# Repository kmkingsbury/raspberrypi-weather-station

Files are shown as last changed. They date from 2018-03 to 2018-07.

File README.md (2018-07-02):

# raspberry-pi-weatherstation

Rebuild of a Pi powered weather station. The origial I did an instructable for (https://www.instructables.com/id/Complete-DIY-Raspberry-Pi-Weather-Station-with-Sof/) this one uses all off the self parts.

And wrote up a few thoughts about the project on my blog as well: 
https://spaceman-labs.com/2018/07/raspberry-pi-weather-station-mk2/

Uses a few standard sensors to track weather data:
- Temperature - comes from 2 sensors the BMP and the DHT.
- Soil temperature
- Soil humidity
- Light - via a photoresistor. The Higher the number the darker out.
- Pressure
- Humidity
- 2 Air sensors - One does more dust and smoke, air quality. The other looks for gases like propane and butane.
- Wind speed
- Wind dir
- Rain Gauge
- Lightning detector - Currently having issues so commented out.

The analog sensors run through the MCP3008 chip to get converted to a digital reading.

The wiring and circuit boards are in the schematics directory and is a Fritzing file. There are also PDFs I used to print the PCB to thermal transfer paper and burn the Copper circuit boards. There are two boards: 1 in the main station for the MCP3008 A/D converter and photo resistor, and the 2nd is a "remote" unit that goes in the Amrite housing and does the air sensing, pressure, temp, and humidity, via 2 air sensors, the DHT, and the BMP.

Data is logged to a postgres table as well as a CSV file and the CSV file is rotated out nightly. The log file also contains some of the data and other debug statements.

Some frontend code is supplied to display/graph the data using Google Charts. This uses PHP to write javascript code, so it's far from ideal.
Also needs more reusable code, since a bug or change needs to go across all the pages and I've currently not been fixing that. Timeframes are roughly 24 hrs and 7-days (for the files ending in 2). Currently very buggy and titles/labels aren't very accurate (months in javascript start at 0 not 1). Will probably rewrite the frontend to something like NodeJS that will integrate easier with Google Charts (or another plotting package)

I used Gitlab and gitlab pipelines to do some automated CI and testing so the gitlab-ci is provided for some of that.

# Contents
Name | Description
-----|------------
`bom.md` | Bill of Materials - List of parts, counts, approximate prices and where to find.
`schematics/`| Fritzing Schematics for electronics
`station-code/`| Python3 Code.
`station-code/collectweather.py`| Main code for collecting weather data.
`README.md`|This file
`LICENSE`|Apache 2.0 License
`frontend/`| Docker container from running PHP scripts to display the data.
`structure.sql` | Postgresql Data schema.

# Pi Setup
- apt-get update
- apt-get upgrade
- apt-get dist-upgrade
- apt-get autoremove
- Turn on Interfacing Options:
    - SPI
    - I2C
    - 1-wire

# Python Packages
- sudo apt-get install libyaml-dev
- pip3 install pyyaml
- pip3 install structlog
- pip3 install numpy
- sudo apt-get install build-essential python-dev python3-dev
- sudo pip install psycopg2

# Postgresql Setup
- sudo apt-get install postgresql-9.6
- apt install postgresql libpq-dev postgresql-client postgresql-client-common
- sudo update-rc.d postgresql enable
- sudo su postgres
- createuser weatherstation -P --interactive
- createdb weatherstation
- create table using structure.sql
- GRANT ALL PRIVILEGES ON TABLE weatherdata TO weatherstation;
- https://www.howtoforge.com/tutorial/postgresql-replication-on-ubuntu-15-04/

# 3rd Party Sensor Modules:
Add SSH key:
```
eval $(ssh-agent -s)
ssh-add ~/.ssh/other_id_rsa
```
Checkout Modules, run sudo python setup.py install
```
git clone https://github.com/PrzemoF/bmp183.git
git clone git://gist.github.com/3151375.git
git clone https://github.com/adafruit/Adafruit_Python_DHT.git
git clone https://github.com/adafruit/Adafruit_Python_GPIO.git
git clone https://github.com/adafruit/Adafruit_Python_MCP3008.git
```

Docker testing image:
```
docker build -t gitlab:4567/lab-projects/raspberry-pi-weatherstation .
```

# Components
- Leverages gitlab and pipelines to do tasks
- Started with Database is Postgresql and the pgadmin interface to get GUI
representation.

# License and Authors

Author:: Kevin Kingsbury ([@kmkingsbury](https://twitter.com/kmkingsbury))

Apache 2.0

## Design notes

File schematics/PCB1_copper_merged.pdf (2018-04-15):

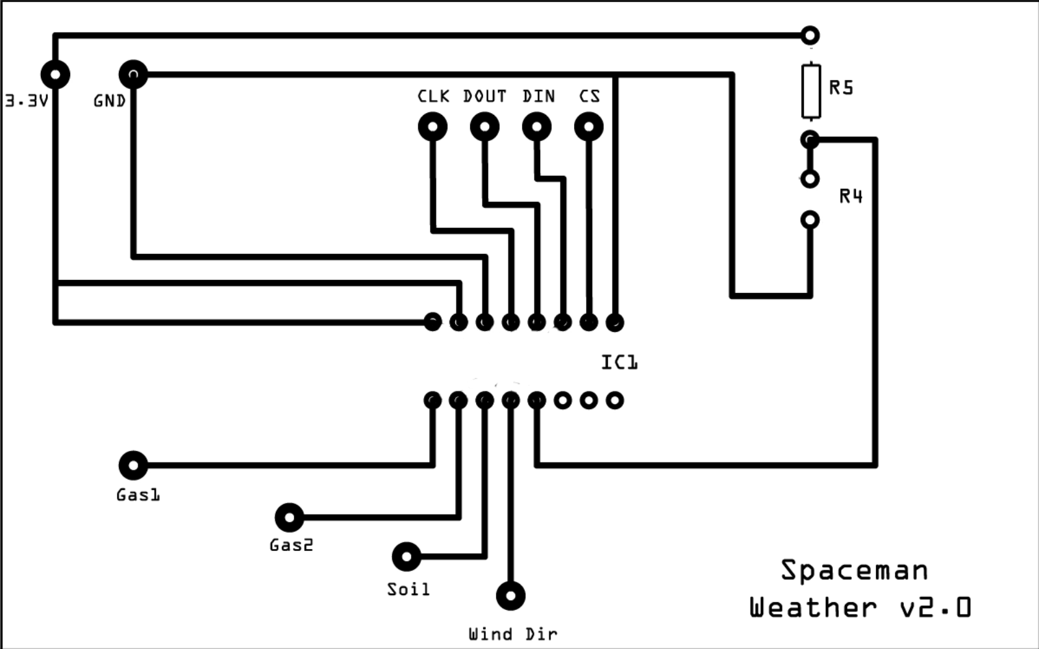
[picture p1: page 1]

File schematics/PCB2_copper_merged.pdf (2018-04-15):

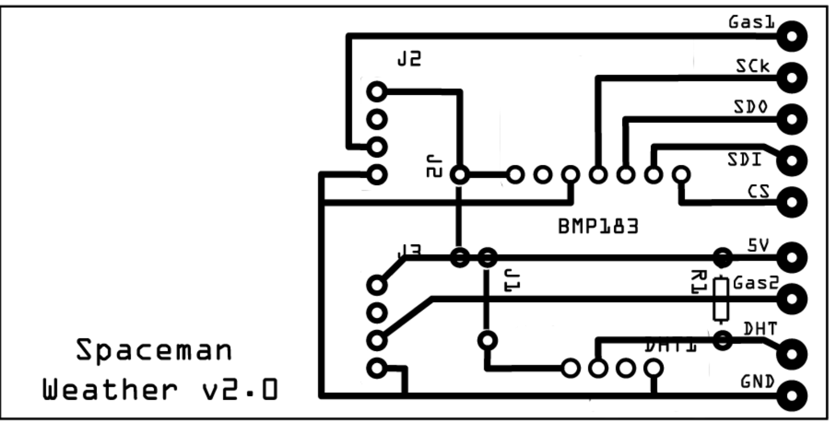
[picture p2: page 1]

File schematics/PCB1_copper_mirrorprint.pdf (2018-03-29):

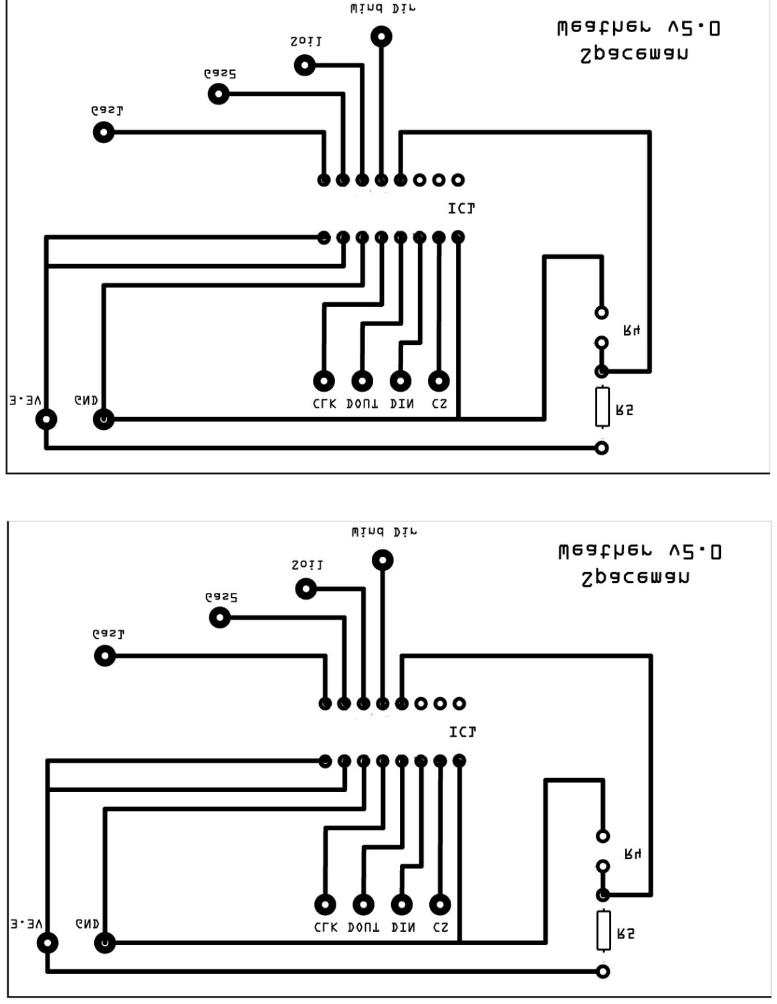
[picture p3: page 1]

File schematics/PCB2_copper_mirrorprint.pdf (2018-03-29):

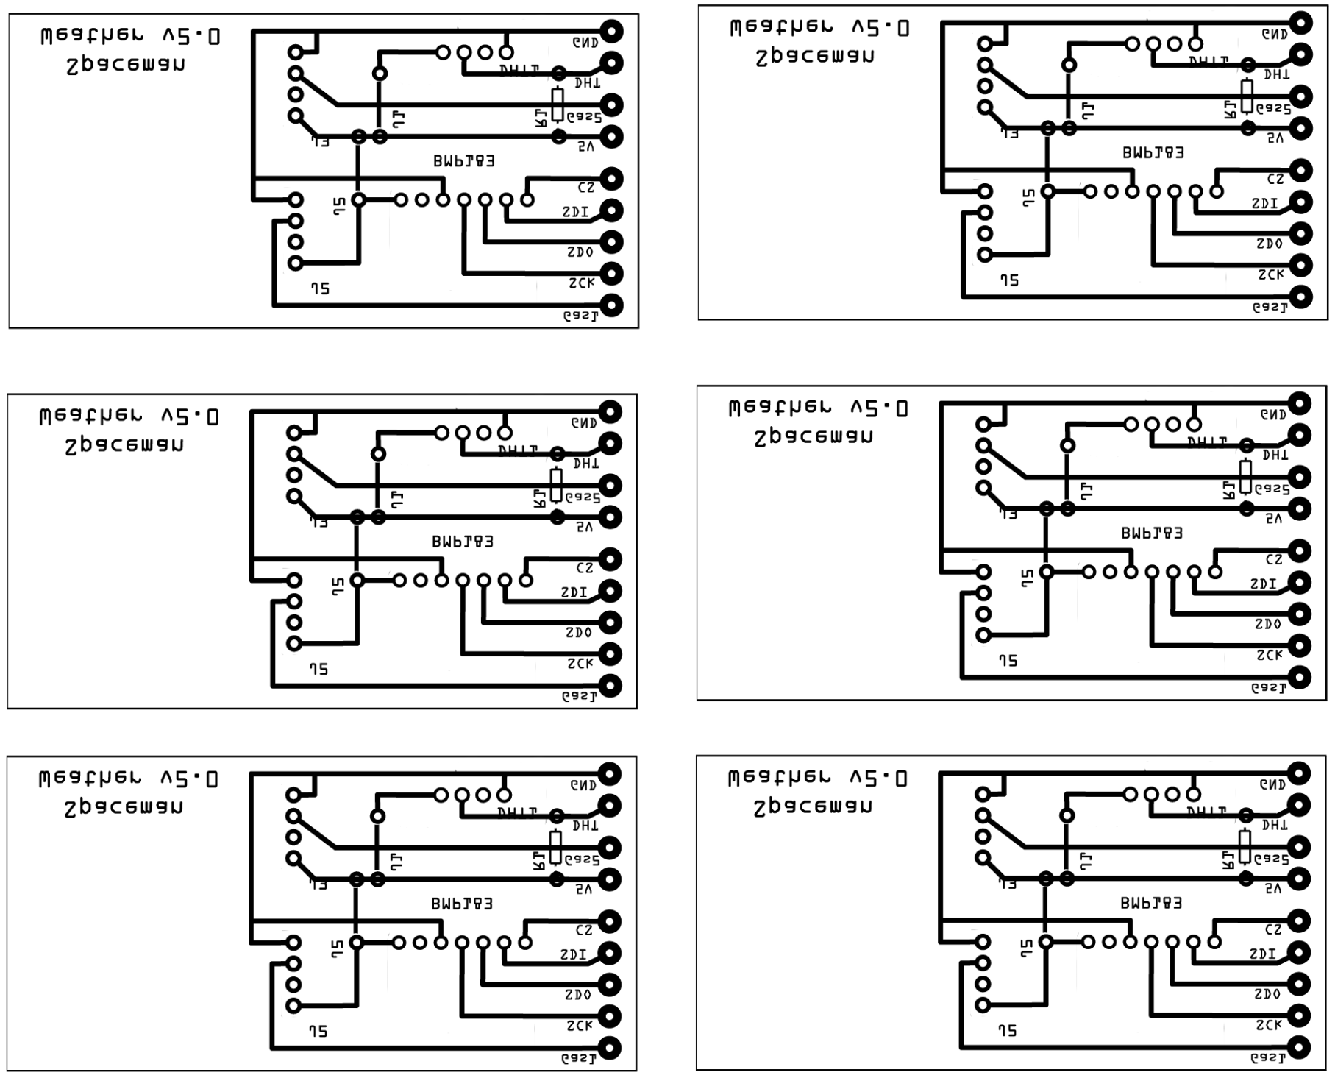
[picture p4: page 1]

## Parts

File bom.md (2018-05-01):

# Bill of Materials

Item | Count | Price | Url/Source
-----|-------|-------|-----------
Arduino | 1 | $19.00 | http://world.arduino.org/en/arduino/arduino-uno-smd-rev3.html
Waterproof DS18B20 Digital temperature sensor | 1 | |
BMP183 - barometric pressure and temperature | 1 | | https://www.adafruit.com/product/1900
DHT11 Temperature & Humidity | 1 | | https://www.adafruit.com/product/386
Soil Moisture Sensor | 1 | | https://www.sparkfun.com/products/13322
SainSmart TGS2600 Air Contaminants | 1 | |
Sunfounder MQ-2 Gas Sensor Module | 1 | |
Wind and Rain Sensors | 1 | | https://www.sparkfun.com/products/8942
AcuRite 06054M Temperature & Humidity Solar Radiation Shield | 1 | | http://a.co/5gr22Gu
Ribbon cable
Copper PC Board 12 x 12 Single Sided | 1 | | http://a.co/jdnRazi
HAMMOND 1591ASBK ENCLOSURE, MULTIPURPOSE, ABS, BLACK | 1 | | http://a.co/6SK6K87

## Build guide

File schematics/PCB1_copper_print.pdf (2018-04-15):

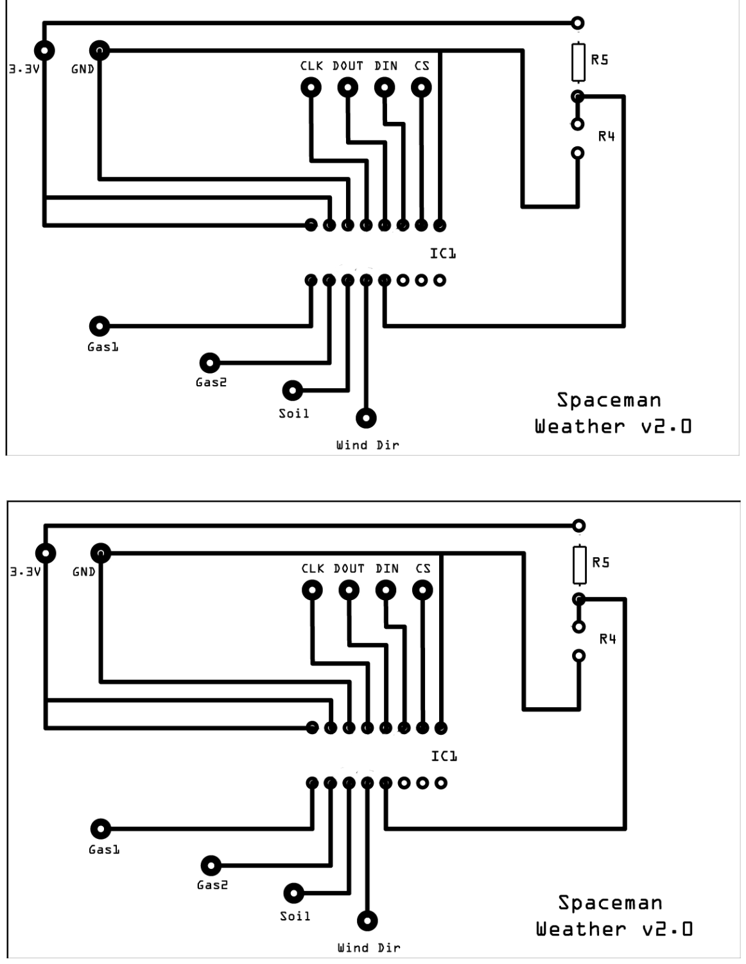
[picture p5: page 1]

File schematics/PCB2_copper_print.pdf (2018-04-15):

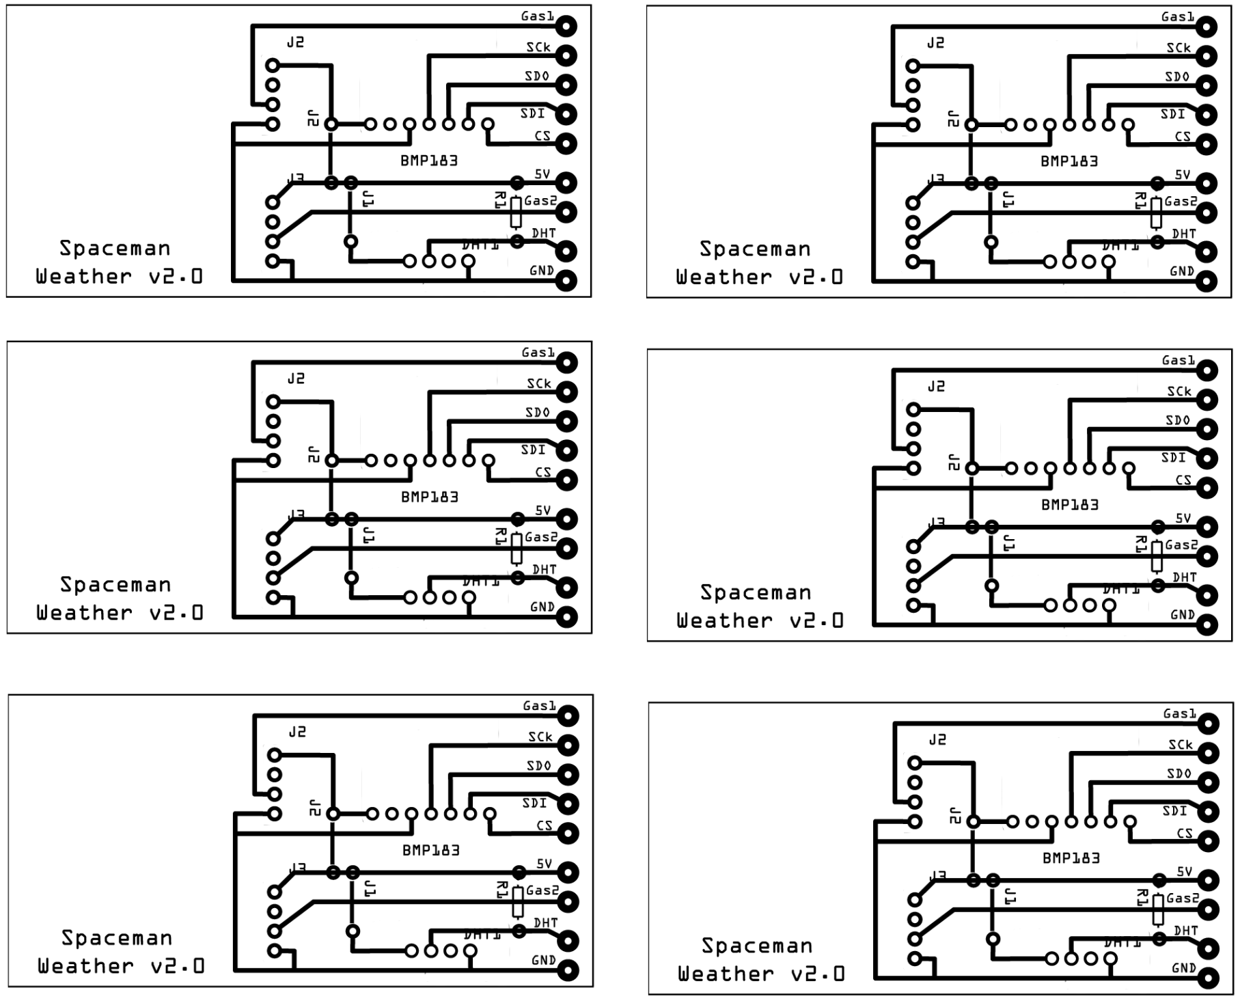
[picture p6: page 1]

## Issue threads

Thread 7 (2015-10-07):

gps/anemometer

OKenobi, 2015-10-07:
Hi there. This is a nice project, indeed. Great job.
I just want to save me some time by not building the wind speed and rain collector. Do you think these items will work with the rest of the components you used? (see links below, please):

GPS:
http://www.adafruit.com/product/746

Anemometer:
http://www.adafruit.com/product/1733

Couldn't find anything as for rain collector bucket that comes pre-assembled and to empty itself.

Thank you.

kmkingsbury, 2015-10-09:
Yes, looks like those will totally work.

There's also these guys to get the whole set without making them. I picked one up:
https://www.sparkfun.com/products/8942
And here:
http://www.kr4.us/weather-meters.html

OKenobi, 2015-10-09:
Thank you. I'll definitely look into it.

Closed 2015-10-09.

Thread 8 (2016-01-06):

stuck in the middle...

OKenobi, 2016-01-06:
Happy New Year, Kevin!

Hope you'll have a blast in 2016.

I'm planning to build the weather station project you've created. got the parts but I'm stuck. I REALLY need your help, brother!
As not so experienced (yet :)) I need some guidlines connecting my components. following the diagram .fzz.file didn't help me much. I hope that you'll help me build this as I already invested time and money towards this great project.

What I have purchased so far:
RPI2/Raspberry Pi camera
Adafruit BMP180 pressure sensor
Adafruit DHT 22 humidity sensor
Adafruit MCP3008
Sparkfun Weather Meater
https://www.sparkfun.com/products/8942 (got this just to save time building it)

tested individually BMP180 and DHT22 work fine, connected to Rpi2 GPIO as:
BMP180:
VIN - Pin #1
GND - Pin #6
SCL - Pin #5
SDA - Pin #3

DHT22:
VDD - Pin #1
DATA - Pin #4
NULL
GND - Pin #6

I don't use a GPS and light sensor; What I don't know where to connect:
the Tipping Bucket Rain Gauge (2 wire conductor RJ11)
the Wind Vane (4 wire conductor on RJ11); (the Anemometer gets connected to Wind Vane with a 2 wire conductor RJ11, I guess).
I know your code is using BMP183, which is an SPI sensor as opossed the one I've purchased. Can you please give me some instructions so I can finish this? I don't want to give up on this, as I said, I've found it amazing, but I'm really stuck right now. Hope you understand my pain :)

thank you, much appreciated and looking fwd hearing from you!

Ovi
TangoRom@yahoo.com

zxPILEDRIVERxz, 2016-01-07:
You can easily set the GPS coordinates manually in the code or remove them entirely.
Rain Bucket -> Just connect one of the two wires to the pin indicated in your code (the interrupts).
Wind Vane -> I took my wind vane apart to determine which two wires i needed. I think mine were the red and black). I gave one side (Black i think) 3.3v (assuming thats what your MCP3008) is getting. The other (Red) goes to ground. In line with the Vin I have a wire going to channel 3 on the MCP3008.
Anemometer -> same as rain bucket (I think yellow and green).

MCP3008 -> http://www.raspberrypi-spy.co.uk/2013/10/analogue-sensors-on-the-raspberry-pi-using-an-mcp3008/ That link should give you a decent idea at what you are looking at. Remember, in the code as is, we are not using SPI for the MCP3008 so that link should only be used for understanding of wiring.

Software -> I had a look here and brought some of the conversions etc for windspeed: https://github.com/switchdoclabs/WeatherPi
https://github.com/switchdoclabs/SDL_Pi_Weather_80422

Notes:
-I used a 10k resistor in line with the vin side of the wind vane a lot like you would with the light sensor.
-The MCP3008 gives you a value ranging from 0 - 1023 based on voltage on that channel. You will need to be able to convert that to voltage and then into degrees (in the case of the windvane). You can find other methods for changing degrees into capital wind direction if you are interested in that.

Ex: (Only code relevant to windvane included) some of this is unnecessary.
```
GPIO.setmode(GPIO.BOARD)
SPICLK = 23 #17
SPIMISO = 21 #24
SPIMOSI = 19 #25
SPICS = 24 #27
winddir_adc = 2

# read SPI data from MCP3008 chip, 8 possible adc's (0 thru 7)
def readadc(adcnum, clockpin, mosipin, misopin, cspin):
        if ((adcnum > 7) or (adcnum < 0)):
                return -1
        GPIO.output(cspin, True)

        GPIO.output(clockpin, False)  # start clock low
        GPIO.output(cspin, False)     # bring CS low

        commandout = adcnum
        commandout |= 0x18  # start bit + single-ended bit
        commandout <<= 3    # we only need to send 5 bits here
        for i in range(5):
                if (commandout & 0x80):
                        GPIO.output(mosipin, True)
                else:
                        GPIO.output(mosipin, False)
                commandout <<= 1
                GPIO.output(clockpin, True)
                GPIO.output(clockpin, False)

        adcout = 0
        # read in one empty bit, one null bit and 10 ADC bits
        for i in range(12):
                GPIO.output(clockpin, True)
                GPIO.output(clockpin, False)
                adcout <<= 1
                if (GPIO.input(misopin)):
                        adcout |= 0x1

        GPIO.output(cspin, True)

        adcout >>= 1       # first bit is 'null' so drop it
        return adcout

# convert light into percent
def ConvertVoltage(data, supplyVolt):
  voltage = data/1024. * supplyVolt #// convert to voltage value
  return voltage

def ConvertPercent (data, supplyVolt, places):
  percent = (data / supplyVolt) * 100
  percent = round(percent,places)
  return percent

def fuzzyCompare(compareValue, value):
    VARYVALUE = 0.05
    if ( (value > (compareValue * (1.0-VARYVALUE)))  and (value < (compareValue *(1.0+VARYVALUE))) ):
        return True
    return False

def voltageToDegrees(value, defaultWindDirection):
    ADJUST3OR5 = 0.66
    PowerVoltage = 3.3
    if (fuzzyCompare(3.84 * ADJUST3OR5, value)):
        return 0.0
    if (fuzzyCompare(1.98 * ADJUST3OR5, value)):
        return 22.5
    if (fuzzyCompare(2.25 * ADJUST3OR5, value)):
	return 45
    if (fuzzyCompare(0.41 * ADJUST3OR5, value)):
	return 67.5
    if (fuzzyCompare(0.45 * ADJUST3OR5, value)):
	return 90.0
    if (fuzzyCompare(0.32 * ADJUST3OR5, value)):
	return 112.5
    if (fuzzyCompare(0.90 * ADJUST3OR5, value)):
	return 135.0
    if (fuzzyCompare(0.62 * ADJUST3OR5, value)):
	return 157.5
    if (fuzzyCompare(1.40 * ADJUST3OR5, value)):
	return 180
    if (fuzzyCompare(1.19 * ADJUST3OR5, value)):
	return 202.5
    if (fuzzyCompare(3.08 * ADJUST3OR5, value)):
 	return 225
    if (fuzzyCompare(2.93 * ADJUST3OR5, value)):
	return 247.5
    if (fuzzyCompare(4.62 * ADJUST3OR5, value)):
	return 270.0
    if (fuzzyCompare(4.04 * ADJUST3OR5, value)):
	return 292.5
    if (fuzzyCompare(4.34 * ADJUST3OR5, value)): # chart in manufacturers documentation wrong
	return 315.0
    if (fuzzyCompare(3.43 * ADJUST3OR5, value)):
	return 337.5
    return defaultWindDirection  # return previous value if not found

def windDirectionFromDegrees (Degrees):
    if (348.75 <= Degrees <= 360.00):
        hour1WindDirection = "N"
    elif (0 <= Degrees <= 11.25):
        hour1WindDirection = "N"
    elif (11.25 < Degrees <= 33.75):
        hour1WindDirection = "NNE"
    elif (33.75 < Degrees <= 56.25):
        hour1WindDirection = "NE"
    elif (56.25 < Degrees <= 78.75):
        hour1WindDirection = "ENE"
    elif (78.75 < Degrees <= 101.25):
        hour1WindDirection = "E"
    elif (101.25 < Degrees <= 123.75):
        hour1WindDirection = "ESE"
    elif (123.75 < Degrees <= 146.25):
        hour1WindDirection = "SE"
    elif (146.25 < Degrees <= 168.75):
        hour1WindDirection = "SSE"
    elif (168.75 < Degrees <= 191.25):
        hour1WindDirection = "S"
    elif (191.25 < Degrees <= 213.75):
        hour1WindDirection = "SSW"
    elif (213.75 < Degrees <= 236.25):
        hour1WindDirection = "SW"
    elif (236.25 < Degrees <= 258.75):
        hour1WindDirection = "WSW"
    elif (258.75 < Degrees <= 281.25):
        hour1WindDirection = "W"
    elif (281.25 < Degrees <= 303.75):
        hour1WindDirection = "WNW"
    elif (303.75 < Degrees <= 326.25):
        hour1WindDirection = "NW"
    elif (326.25 < Degrees < 348.75):
        hour1WindDirection = "NNW"
    else:
        hour1WindDirection = nil
    return hour1WindDirection
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
akmahusaini, 2016-12-06:
do you know the coding of wind vane with adc mcp3008? i have a project for weather station. please help us

orega35, 2017-01-24:
Hello, has anyone managed to reproduce this station? I still have a lot of questions about wiring (ldr, mpc3008 ...) all sensors have to go through the mpc3008? i use the maplin wind vane.

OKenobi, 2017-01-25:
I totally gave up. Mine was so close to be completed but got lots of errors running the code, I personally couldn't fix it.I've switched to this one, less headache:
GroveWeatherPi - Solar Raspberry Pi based Weather Station - No Soldering Required (Updated October 24, 2016)

|
|
|
|   |    |

   |

  |
|
|    |
GroveWeatherPi - Solar Raspberry Pi based Weather Station - No Soldering Re...
 Building a Solar Powered Raspberry Pi Weather Station - GroveWeatherPi (Updated October 25, 2016)The Raspberry P...  |   |

  |

  |

"A clever person solves a problem. A wise person avoids it."

A.Einstein

      From: orega35 <notifications@github.com>
 To: kmkingsbury/raspberrypi-weather-station <raspberrypi-weather-station@noreply.github.com>
Cc: OKenobi <tangorom@yahoo.com>; Author <author@noreply.github.com>
 Sent: Tuesday, January 24, 2017 4:33 AM
 Subject: Re: [kmkingsbury/raspberrypi-weather-station] stuck in the middle... (#8)

Hello, has anyone managed to reproduce this station? I still have a lot of questions about wiring (ldr, mpc3008 ...) all sensors have to go through the mpc3008? i use the maplin wind vane.—
You are receiving this because you authored the thread.
Reply to this email directly, view it on GitHub, or mute the thread.

orega35, 2017-01-25:
too bad. I teach in a college and in club we try to run this station with server. It seems to me very well, but it is true that it lacks some explanations to the " instructables". I will continue....

OKenobi, 2017-01-26:
i know... but hey, good luck and please keep me posted in case you get to the bottom of it;
thanks
--Obiwan
 

"A clever person solves a problem. A wise person avoids it."

A.Einstein

      From: orega35 <notifications@github.com>
 To: kmkingsbury/raspberrypi-weather-station <raspberrypi-weather-station@noreply.github.com>
Cc: OKenobi <tangorom@yahoo.com>; Author <author@noreply.github.com>
 Sent: Wednesday, January 25, 2017 2:50 PM
 Subject: Re: [kmkingsbury/raspberrypi-weather-station] stuck in the middle... (#8)

too bad. I teach in a college and in club we try to run this station with server. It seems to me very well, but it is true that it lacks some explanations to the " instructables". I will continue....—
You are receiving this because you authored the thread.
Reply to this email directly, view it on GitHub, or mute the thread.

zxPILEDRIVERxz, 2017-01-26:
@orega35 Perhaps you could precise to me exactly what you need help on. I'm going to go ahead and begin to answer based on your previous post.
Hello, has anyone managed to reproduce this station?
 - Yes, I have.

Wiring the MCP3008:
 - http://www.raspberrypi-spy.co.uk/2013/10/analogue-sensors-on-the-raspberry-pi-using-an-mcp3008/

All sensors have to go through MCP3008:
 - Only the sensors that you need to read a voltage level from, need to be wired to the MCP3008 (The wind vane and the light dependent resistor). You are just looking for high or low from the rain gauge and anemometer; therefore, those can be wired to digital pins through a current limiting resistor (10k) Explanation: the gpio of raspberry pi can only sink or source so much which is why you need the resistor (resistors reduce current flow. A great place to see this concept in action is: http://www.falstad.com/circuit/).
An additional weather project that may help: http://www.instructables.com/id/Complete-DIY-Raspberry-Pi-Weather-Station-with-Sof/?ALLSTEPS

Wiring the Light dependent resistor.
 - The instructions on this project are not that great about the wiring. Look for instructions online for each component. For example, reading light dependent resistor with MCP3008: http://www.pibits.net/code/read-ldr-raspberry-pi-using-mcp3008.php

orega35, 2017-01-26:
OK thanks for your answer. I'll test it all!
Can I contact  you again if necessary?

zxPILEDRIVERxz, 2017-01-26:
Of course, here is my site if it gives you any inspiration.

http://weather.danielpile.com:8080/

orega35, 2017-01-29:
Great job !

I will see what my students will produce. I must not give them too many
examples!

Le 26/01/2017 à 20:10, zxPILEDRIVERxz a écrit :
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

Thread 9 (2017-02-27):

Can't get the website to work

ergcgs, 2017-02-27:
After much trials and tribulations, I finally got the raspberryweatherstation.py to read the values.

I got the website to show up, with the graphs, moon phase, record high and low.  But I cannot get the current humidity, temp, pressure, rainfall, light to show up.  It is all zeros.

I cannot get the graphs to populate any values.  I uncommented the lines:

<code>$a = print_r($result);</code>
<code>print "preT: ". print_r($result['data']['temperature'], true);</code>

in the index.php file, and it says everything in my database is NAN.

Does anybody have a working index.php they would be willing to share?

I added the following to my raspberrypiweatherstation.py to get it to update the database:

<code>#      csv.writerow(data)</code>
<code>#Write to wundergrounddata.RRD</code>
<code>                UpdateRRD = ('/usr/bin/rrdtool update /var/www/html/weatherdata.rrd N:' + str(bmptemp) + ':' + str(trueRH) + ':' + str(light) + ':' + str(winddir) + ':' + str(windspeed) + ':' + str(bmppressure) + ':' + str(rain))</code>
<code>                os.system(UpdateRRD)</code>

which generates:
<code>/usr/bin/rrdtool update /var/www/html/weatherdata.rrd N:71.24:57.7999992371:16:10:0:990.21:0</code>

which doesn't return any errors...

The output of my raspberrypiweatherstation.py looks like this in the terminal:

<code>GPS reading</code>
<code>latitude     0.0</code>
<code>longitude    0.0</code>
<code>time utc       +  nan</code>
<code>altitude (m) nan</code>
<code>time system 2017-02-27 00:04:56</code>
<code>Temperature:  21.8 deg C</code>
<code>Pressure:  990.21  hPa</code>
<code>Temp=20.8*C  Humidity=57.4%</code>
<code>Humidity     57.4000015259 %</code>
<code>Light:16</code>
<code>Wind:9</code>
<code>Data:  ['2017-02-27 00:04:56', XXXXXX, XXXXXX, 71.24000000000001, 57.400001525878906, 990.19, 16, 9, 0, 0]</code>
<code>/usr/bin/rrdtool update /var/www/html/weatherdata.rrd N:71.24:57.4000015259:16:9:0:990.19:0</code>

BTW:  What is up with the formatting here?  That was totally bonkers.

kmkingsbury, 2017-02-27:
Might have to take a closer look but first pass/gut reaction is that if the values are there, the command is  ok, then it might either be permissions on the RRD file and/or something like SELinux which may prevent the data from being properly "imported"/"entered". Especially because it is going to the /var/www/html dir.

ergcgs, 2017-02-27:
Ok, so i got home from work today and just refreshed the website and voila, there is some data!

The header data at the top populated, the temperature graph populated, but it was very jagged. I clicked on the past hour and there were a lot of gaps in the data.   I checked the database values and there are a lot of NAN values in the middle of the temps in the database.  I wonder if the 1 second refresh interval in raspberrypiweatherstation.py was too quick.  I changed that to 3 seconds and will check back in a bit to see how it turns out.

None of the other graphs would populate though, so I am hoping that the longer interval will let the values record to the RRD more successfully.

ergcgs, 2017-03-02:
Ok, so changing the refresh interval to 3 seconds didnt work at all.  The pi wouldnt record any data.  It made everything NAN.  At 1 second intervals it records data like this for all of the sensors.

<code>T: Array</code>
<code>(</code>
<code>    [1488371225] => NAN</code>
<code>    [1488371230] => 55.5946699</code>
<code>    [1488371235] => NAN</code>
<code>    [1488371240] => 70.785952066667</code>
<code>    [1488371245] => NAN</code>
<code>    [1488371250] => NAN</code>
<code>    [1488371255] => NAN</code>
<code>    [1488371260] => NAN</code>
<code>    [1488371265] => 74.67296886</code>
<code>    [1488371270] => NAN</code>
<code>    [1488371275] => 77.91850346</code>
<code>    [1488371280] => 83.3</code>
<code>    [1488371285] => 83.3</code>
<code>    [1488371290] => NAN</code>
<code>    [1488371295] => NAN</code>
<code>    [1488371300] => NAN</code>
<code>    [1488371305] => 83.3</code>
<code>    [1488371310] => 83.3</code>
<code>    [1488371315] => NAN</code>

Is this what it is supposed to look like?  I would think it would have values for each entry.

Swift797, 2017-04-29:
I'm having similar problems, took a bit but I've gotten the Python script to work however RRDtool is not set up in the script... weird. Not sure how the PHP script is supposed to receive the info, is it from the line

`$result = rrd_fetch( "./wundergrounddata.rrd", array( "AVERAGE", "--resolution", "300", "--start", "-10min", "--end", "-5min" ) );`

but `./wundergrounddata.rrd` is supposed to be `/weatherdata.rrd`?

Would be great if we could get some help on this :).

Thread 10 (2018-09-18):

BMPxxx Wiring

wscrivens, 2018-09-18:
I'm having a problem getting the barometer/temperature sensor to work.  Two years ago I built the original version and with much fussing I got it to work with a BMP180 sensor from Spark Fun.  The hardware was set aside and repurposed, but with the start of Hurricane season (I live in Florida) I decided to resurrect it.  All of the old code was lost, so I downloaded the new code from Github.  The wiring for the new version uses a BMP183 and a Raspberry pi model 3 (with the 40-pin connector) and the terminology for the pin names is different.  I tried various combinations of what I thought was right based on the schematics and photos but nothing worked.  Then I tried to order a BMP183 which is the actual sensor used in the project, but found it was discontinued and got a BME280 instead which was advertised on Adafruit as the replacement.  Still no joy in the wiring. ~/bmp183/measure.py returns garbage.  The sensor DOES work correctly with Adafruit's BMP280 software, so now I'm left with two choices:
- Revise all the software to use Adafruit's library
- find a pinout that will work with the software in this project.
Years ago I coded in C, and more recently Visual Basic, but I'm a relative neophyte in Python, so the first option would be more intellectually challenging but more time consuming.

Can anyone provide the wiring for a BME280 with an old (28 pin) connector on the pi?

Thanks for your help.
Walt

kmkingsbury, 2018-09-19:
Couple of things to check/try:
1. The MODE matters, my code uses BCM so when referring to pins it uses the GPIO names, like GPIO6 rather than physical pin 6 (which is what BOARD mode uses). That might be a cause of the differences.

2. For the BMP280 it uses I2C so need to make sure that's enabled on the pi in the raspi-config advanced options, probably is if the "other" code is working, but something to check.

3. Here's the mappings between the BMP183 and the Pi v3 and what I think your mappings need to be.
(I used this diagram as reference for the Pi B v 1.0 and 2.0: https://raspberrypi.stackexchange.com/questions/12966/what-is-the-difference-between-board-and-bcm-for-gpio-pin-numbering)

My BMP183 uses...
VIN this goes to 5V.
GND to GND
Nothing for the 3.3v
SCK this went to GPIO6 (pin 16)
CS this went to GPIO13(pin 17)
SDI this went to GIPO16(pin 23)
SDO this went to GPIO12(pin 25)

From that diagram (and the Adafruit example Python code) I think the mapping should be:
VIN this goes to 5V.
GND to GND
SCK to the SPI0_SCLK GPIO 11 (pin 23)
CS the tutorial has this going to Pin 5 on the PI which would be GPIO1 on v1.0 of the B, and GPIO3 on v2.0, but both are physical pin 5.
SDI to SPI0_MOSI GPIO10 (pin 19)
SDO to SPI0_MISO GPIO 9 (pin 21)

Just a note that in my code those are the "default" pins but they can be changed to something else by setting the correct GPIO numbers in the config.yaml file.

Hopefully that helps.

wscrivens, 2018-10-07:
Thanks.  Both of those pin assignments gave me "Remote I/O Error" messages.

I took a look at the 28-pin header adapter that came with my pi to plug into a breadboard.  Physical pin 3 on the header is labeled "SDA" - I connected it to SDI on the BME280.  Physical pin 5 is labeled "SCL" - I connected that to SCK on the BME280.  Now collectweather.py runs but is giving me questionable results, temp 80.6 (which is about right in Fahrenheit) and pressure is 0.

I'm confused by the pin numbers used by the program.  Are they physical pins on the header, or some logical mapping?

All of which is only a part of the final battle.  Once I get the python code itself working, I haven't a clue where to put the rest of the files to get the web server running.  Is that documented anywhere?

Thanks,
Walt

wscrivens, 2018-10-09:
Thanks for your quick reply.  I haven't been able to work on this for a couple of weeks, and I read your message too hastily, so I have deleted my previous reply.  I'm still plodding along, learning as I go (which is my main objective here).  I'll post my progress when I have something to report or ask.

Thanks :-)

Walt

wscrivens, 2018-10-10:
OK I'm stuck again.  Please, I'm not asking you to teach me Python GPIO, just point me to some resources.  I've spent several hours on Adafriut and Sourceforge but I can't find the information I'm searching for.

Here's where I'm at:
I connected the BME280 according to your recommendation and modified config.yaml accordingly.  Now I'm getting results but they are wrong.  (Barometer 38, Temperature 241).  I've been studying the code in collectweather.py, especially around line 500 where you are using functions like sensor.read_temperature() but I can't find where the functions are defined.
Also, a little earlier in the code, you use functions like GPIO.setup(cfg.configs['windspeed']['pin'], GPIO.IN, pull_up_down=GPIO.PUD_UP) and I don't know where cfg.configs comes from.

If all of this is basic Python101, just ignore me and I'll move on.  As I think I said, I have experience coding in c (eons ago) and writing Android code more recently, but I'm finding Python and the libraries you are using to be a major challenge.

TIA for your help!

Walt

zxPILEDRIVERxz, 2018-10-10:
@kmkingsbury whoa, this project has changed a lot from version 1! Unfortunately, I have allowed my project to decay because of poor initial planning (I guess I was very new to these things then).

@wscrivens, have you tried isolating your problem? For example, just look up "how to use BME280 with Raspberry Pi"? It looks like there are multiple python libraries for the BME280 including one from Adafruit so maybe that is where I would start (https://learn.adafruit.com/adafruit-bme280-humidity-barometric-pressure-temperature-sensor-breakout/python-circuitpython-test).. If you can get the BME280 producing accurate results by itself, then you can try to integrate what you learned into this project. Let me know if I'm not helping as I dont want to clutter this thread unnecessarily.

wscrivens, 2018-10-11:
@zxPILEDRIVERxz I think we're in the same place!  I built the original weather station from the Instructable about three years ago, then re-used the pi for something else.  Stupidly, I didn't save the SD card!

The BME 280 works fine with Adafruit's libraries and demo code, but unfortunately they are based on BOARD mode rather than BCM, and I haven't yet been able to figure out how to make the translation.  It seems to be a lot more complex than just pin-mapping.

Walt

zxPILEDRIVERxz, 2018-10-12:
@wscrivens Nice, I feel like you have to be really close then. I dont have a BME280 so its hard for me to understand exactly what needs to be done. I guess what I'm wondering is..

Are you now using Adafruit's BME 280 library in collectweather.py?
For example, at the beginning of the file:
`
import board
import busio
import digitalio
import adafruit_bme280
`

And then in main:
`
spi = busio.SPI(board.SCK, MOSI=board.MOSI, MISO=board.MISO)
cs = digitalio.DigitalInOut(board.D5)
bmp = adafruit_bme280.Adafruit_BME280_SPI(spi, cs)
`

In place of:
`
bmp = bmp183(cfg.configs['bmp183']['pin-sck'],
                 cfg.configs['bmp183']['pin-sdo'],
                 cfg.configs['bmp183']['pin-sdi'],
                 cfg.configs['bmp183']['pin-cs'])
`

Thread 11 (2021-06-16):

Would it support radiation sensor

SoraKasvgano, 2021-06-16:
Dear devs,

as we all know that Japanese is going to pour nuclear  water to the ocean,

why don't we add  radiation sensor to the site,collect water radiation data, to avoid  using  dirty water?

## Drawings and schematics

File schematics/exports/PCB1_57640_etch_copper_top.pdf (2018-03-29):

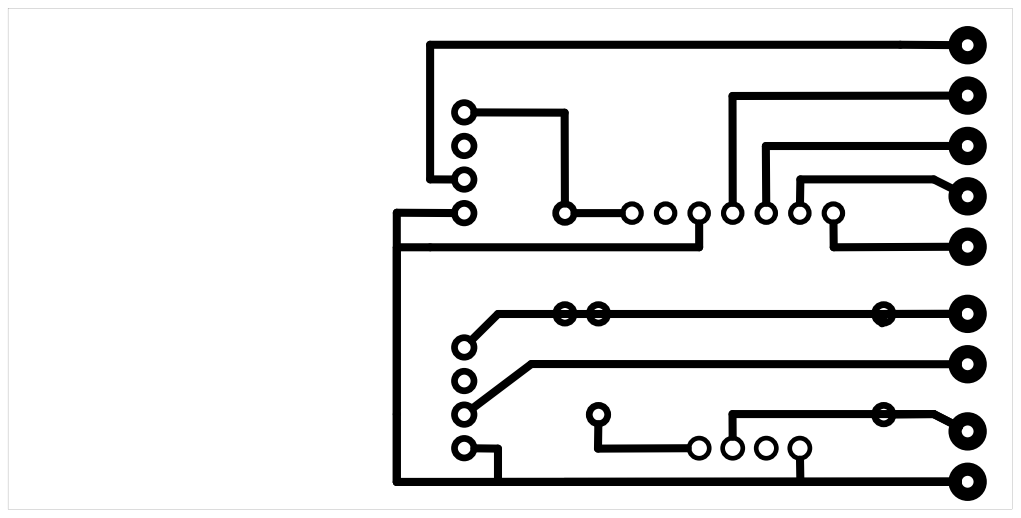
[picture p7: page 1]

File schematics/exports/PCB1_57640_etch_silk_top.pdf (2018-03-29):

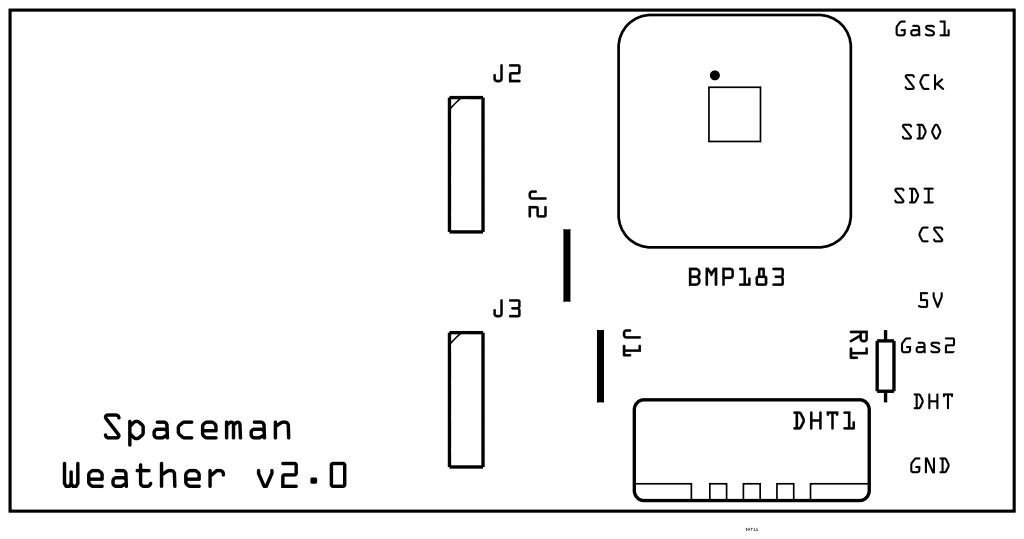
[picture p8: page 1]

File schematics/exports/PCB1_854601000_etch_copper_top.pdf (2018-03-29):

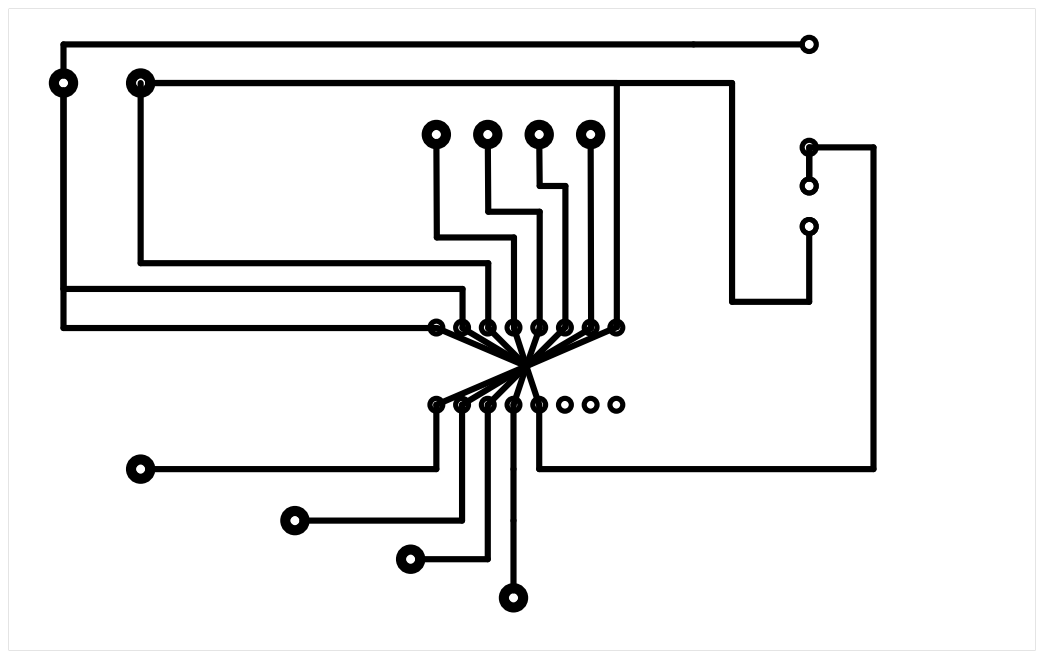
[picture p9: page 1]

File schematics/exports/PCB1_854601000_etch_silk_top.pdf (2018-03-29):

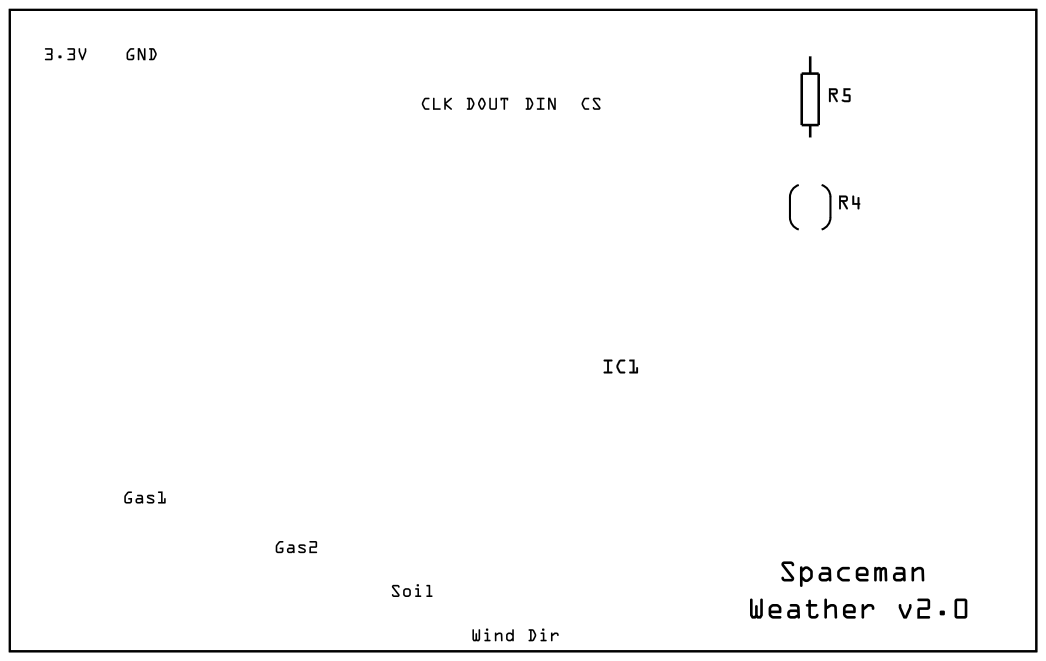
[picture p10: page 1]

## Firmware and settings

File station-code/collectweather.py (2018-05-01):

import sys
import yaml
import RPi.GPIO as GPIO
import time
import datetime
import structlog
from pathlib import Path
import csv
import os
import glob
from daemon import Daemon
from bmp183 import bmp183
import Adafruit_DHT
import Adafruit_GPIO.SPI as SPI
import Adafruit_MCP3008
import psycopg2
# from RPi_AS3935 import RPi_AS3935  # for lightning, not working

os.system('modprobe w1-gpio')
os.system('modprobe w1-therm')

base_dir = '/sys/bus/w1/devices/'
device_folder = glob.glob(base_dir + '28*')[0]
device_file = device_folder + '/w1_slave'


def windEventHandler(pin):
    # print("handling wind speed event")
    data.windspeed += 1


def rainEventHandler(pin):
    # print("handling rain event")
    global lastrainevent
    now = datetime.datetime.now()
    diff = (now-lastrainevent).total_seconds()
    if (diff > 0.25):
        data.rain += 1
    lastrainevent = datetime.datetime.now()


def handle_interrupt(channel):
    time.sleep(0.003)
    global sensor
    reason = sensor.get_interrupt()
    if reason == 0x01:
        print("Noise level too high - adjusting")
        sensor.raise_noise_floor()
    elif reason == 0x04:
        print("Disturber detected - masking")
        sensor.set_mask_disturber(True)
    elif reason == 0x08:
        now = datetime.now().strftime('%H:%M:%S - %Y/%m/%d')
        distance = sensor.get_distance()
        print("We sensed lightning!")
        print("It was " + str(distance) + "km away. (%s)" % now)
        print("")


class CSVWriter:

    def __init__(self, filename='test.csv', header=[]):
        print("CSV init")
        newfile = False
        self._header = header
        self._fileday = None
        self._filename = filename
        outfile = Path(filename)
        if not outfile.is_file():
            # File doesn't exist, will be created, print header too
            print("CSV init file not exist")
            newfile = True
        self.fn = open(filename, 'a')
        self.fileday = int(datetime.datetime.utcnow().day)
        # print("CSV Date:" + str(self._day))
        self.csv = csv.writer(self.fn, delimiter=',')
        # print("Size" + str(len(header)))
        if newfile:
            # new file so print header
            print("CSV init print header")
            self.csv.writerow(self._header)

    def writedata(self, dataobj):
        print("CSV write")
        day = int(dataobj[0][8:10])  # parse string of 1st arrat item
        if (int(self.fileday) != int(day)):

            print("CSV not equal ")
            # usually at 11:59 so UTCnow will get next day.
            dt = datetime.datetime.utcnow()
            filename = "data-"+dt.strftime("%Y-%m-%d") + ".csv"
            print("Newfile: " + filename)
            print("Self Day vs Arg Day:" + str(self.fileday) + "-" + str(day))
            self.fn.close()
            print("CSV after close")
            self = CSVWriter(filename, self._header)
            print("CSV new self")
            self.fileday = int(day)
            # self.csv.writerow(self._header)
            # self.fileday = int(datetime.datetime.utcnow().day)
            # self._day = int(datetime.datetime.utcnow().day)
        print("CSV writerow")
        self.csv.writerow(dataobj)

        print("After:" + str(self.fileday))
        self.fn.flush()
        # print("csv write")
        return self

    def __del__(self):
        print("CSV Del")
        self.fn.close()

    @property
    def fileday(self):
        # Day of Month for rotating CSV file
        """getting"""
        print("Fileday get")
        return int(self._fileday)

    @fileday.setter
    def fileday(self, value):
        print("Fileday setter: "+str(value))
        if int(value) is not None and 0 <= int(value) <= 31:
            self._fileday = int(value)
        else:
            self._fileday = None


class StationConfig:
    """Configuration parser"""
    def __init__(self, file='config.yaml'):
        with open(file, 'r') as ymlfile:
            try:
                self.configs = yaml.load(ymlfile)
            except yaml.YAMLError as exc:
                sys.exit("Fatal: Config file cannot be parsed as correct YAML")


class WeatherDaemon(Daemon):
    def run(self):
        while True:
            time.sleep(.001)


class WeatherData:

    def __init__(self):
        self._timestamp = datetime.datetime.utcnow()
        self._tdelta = 0.00
        self._temp = 0
        self._pressure = 0
        self._humidityDHT = None
        self._temperatureDHT = None
        self._ds18b20temp = None
        self._light = 0
        self._winddir = 0
        self._windspeed = 0
        self._rain = 0
        self._air1 = 0
        self._air2 = 0
        self._soilmoisture = 0
        self._dataformatversion = 1
        self._DHTsuccess = 0

    @property
    def timeUTC(self):
        s = self._timestamp.strftime('%Y-%m-%d %H:%M:%S.%f')
        return s[:-3]

    @property
    def pressureMillibar(self):
        # Raw is Pascals, divide by 100 to get millibar
        """getting"""
        return "%0.1f" % ((self._pressure/100),)

    @property
    def pressureInchesHG(self):
        # Raw is Pascals, divide by 3389.39 you'll get inches-Hg.
        """getting"""
        return "%0.2f" % ((self._pressure/3389.39),)

    @property
    def pressure(self):
        # Raw is Pascals
        """getting"""
        return "%0.2f" % (self._pressure)

    @pressure.setter
    def pressure(self, value):
        if value is not None and 0.0 <= value <= 100000.0:
            self._pressure = value
        else:
            self._pressure = 0.0

    @property
    def air1(self):
        """getting"""
        return self._air1

    @air1.setter
    def air1(self, value):
        if value is not None and 0.0 <= value <= 1024.0:
            self._air1 = value
        else:
            self._air1 = 0.0

    @property
    def windspeed(self):
        """getting"""
        return self._windspeed

    @windspeed.setter
    def windspeed(self, throwaway):
        self._windspeed += 1

    @property
    def rain(self):
        """getting"""
        return self._rain

    @rain.setter
    def rain(self, throwaway):
        self._rain += 1

    @property
    def light(self):
        """getting"""
        return self._light

    @light.setter
    def light(self, value):
        if value is not None and 0.0 <= value <= 1024.0:
            self._light = value
        else:
            self._light = 0.0

    @property
    def winddir(self):
        """getting"""
        return self._winddir

    @winddir.setter
    def winddir(self, value):
        if value is not None and 0.0 <= value <= 1024.0:
            self._winddir = value
        else:
            self._winddir = 0.0

    @property
    def air2(self):
        """getting"""
        return self._air2

    @air2.setter
    def air2(self, value):
        if value is not None and 0.0 <= value <= 1024.0:
            self._air2 = value
        else:
            self._air2 = 0.0

    @property
    def soilmoisture(self):
        """getting"""
        return self._soilmoisture

    @soilmoisture.setter
    def soilmoisture(self, value):
        if value is not None and 0.0 <= value <= 1024.0:
            self._soilmoisture = value
        else:
            self._soilmoisture = 0.0

    @property
    def dataformatversion(self):
        """getting"""
        return self._dataformatversion

    @property
    def ds18b20temp(self):
        """getting"""
        return self._ds18b20temp

    @ds18b20temp.setter
    def ds18b20temp(self, value):
        if value is not None and -40.0 <= value <= 200.0:
            self._ds18b20temp = "%0.2f" % (value,)
        else:
            self._ds18b20temp = 0.0

    @property
    def humidityDHT(self):
        """getting"""
        return self._humidityDHT

    @property
    def temperatureDHT(self):
        """getting"""
        return self._temperatureDHT

    @humidityDHT.setter
    def humidityDHT(self, value):
        if value is not None and 0.0 <= value <= 100.0:
            self._humidityDHT = value
        else:
            self._humidityDHT = 0.0

    @temperatureDHT.setter
    def temperatureDHT(self, value):
        # Store in F, so convert from C:
        if value is not None and 0.0 <= value <= 200.0:
            self._temperatureDHT = "%0.2f" % ((value*1.8)+32,)
        else:
            self._temperatureDHT = 0.0

    @property
    def temp(self):
        """getting"""
        return "%0.1f" % (self._temp)

    @property
    def tempF(self):
        """getting"""
        return "%0.1f" % ((self._temp*1.8)+32,)

    @property
    def tempC(self):
        """getting"""
        return "%0.1f" % (self._temp)

    @temp.setter
    def temp(self, value):
        # Store in F, so convert from C:
        if value is not None and 0.0 <= value <= 200.0:
            self._temp = value
        else:
            self._temp = 0.0

    @property
    def tdelta(self):
        """getting"""
        return "%0.2f" % (self._tdelta)

    @tdelta.setter
    def tdelta(self, value):
        # Store in F, so convert from C:
        if value is not None and 0.00 <= value <= 200.00:
            self._tdelta = value
        else:
            self._tdelta = 0.00

    def exportdata(self):
        return [self.timeUTC, self.tdelta, self.tempF, self.pressureMillibar,
                self.temperatureDHT, self.humidityDHT, self.light,
                self.winddir, self.getwinddir(self.winddir), self.windspeed,
                self.rain, self.ds18b20temp, self.soilmoisture, self.air1,
                self.air2, self.dataformatversion]

    def day(self):
        s = self._timestamp.strftime('%Y-%m-%d %H:%M:%S.%f')
        return int(s[8:10])

    def describedata(self, v=None):
        v = v or self._dataformatversion
        if v == 1:
            return ["Timestamp UTC", "Timedelta sec", "BMP Temp F",
                    "BMP Pressure Millibar", "DHT Temp C", "DHT Humidity %",
                    "Light Count", "Winddir ", "Winddir Lookup",
                    "Windspeed Count", "Rain Count", "Soil Temp",
                    "Soil Moisture", "Air Sensor 1", "Air Sensor 2",
                    "Data Format Version"]
        else:
            return [v]

    def getwinddir(self, windreading):
        winddirtable = {
                        (867, 917): 'W',
                        (816, 866): 'NW',
                        (770, 815): 'WNW',
                        (714, 769): 'N',
                        (644, 713): 'NWN',
                        (598, 643): 'SW',
                        (521, 597): 'SWW',
                        (431, 520): 'NE',
                        (348, 430): 'NNE',
                        (269, 347): 'S',
                        (218, 268): 'SSW',
                        (159, 217): 'SE',
                        (112, 158): 'SES',
                        (90, 112): 'E',
                        (76, 89): 'NEE',
                        (33, 75): 'ESE'
                        }
        for key in winddirtable:
            if key[0] < windreading < key[1]:
                return winddirtable[key]

    @staticmethod
    def ds18b20_read_temp_raw():
        f = open(device_file, 'r')
        lines = f.readlines()
        f.close()
        return lines

    @staticmethod
    def ds18b20_read_temp():
        lines = WeatherData.ds18b20_read_temp_raw()
        while lines[0].strip()[-3:] != 'YES':
            time.sleep(0.001)
            lines = WeatherData.ds18b20_read_temp_raw()
        equals_pos = lines[1].find('t=')
        if equals_pos != -1:
            temp_string = lines[1][equals_pos+2:]
            temp_c = float(temp_string) / 1000.0
            temp_f = temp_c * 9.0 / 5.0 + 32.0
            return temp_c, temp_f


if __name__ == '__main__':

    logger = structlog.get_logger()
    GPIO.setwarnings(False)

    logger.info("Loading Configs...")
    cfg = StationConfig('config.yaml')
    # cfg.dumpcfg()

    logger.info("Getting Data Ready:")
    # Get our CSV Writer ready, pass in the Data Header for 1st line
    dataout = CSVWriter("data-" +
                        datetime.datetime.utcnow().strftime("%Y-%m-%d") +
                        ".csv", WeatherData().describedata())
    try:
        connect_str = "dbname='weatherstation' user='weatherstation' " + \
                  "host='127.0.0.1' password='weatherstation'"
        # use our connection values to establish a connection
        conn = psycopg2.connect(connect_str)

        # create a psycopg2 cursor that can execute queries
        cursor = conn.cursor()

        # create a new table with a single column called "name"
        # cursor.execute("""CREATE TABLE tutorials (name char(40));""")

        # run a SELECT statement - no data in there, but we can try it
        # cursor.execute("""SELECT * from weatherdata""")
        # rows = cursor.fetchall()
        # print("fetch all: " + str(rows))
    except Exception as e:
        print("Uh oh, can't connect. Invalid dbname, user or password?")
        print(e)

    # Sensors
    logger.info("Getting Sensors Ready:")
    # print(cfg.configs['bmp183']['pin-sck'])
    bmp = bmp183(cfg.configs['bmp183']['pin-sck'],
                 cfg.configs['bmp183']['pin-sdo'],
                 cfg.configs['bmp183']['pin-sdi'],
                 cfg.configs['bmp183']['pin-cs'])

    # mcp = Adafruit_MCP3008.MCP3008(clk=cfg.configs['mcp3008']['pin-clk'],
    #                               cs=cfg.configs['mcp3008']['pin-cs'],
    #                               miso=cfg.configs['mcp3008']['pin-miso'],
    #                               mosi=cfg.configs['mcp3008']['pin-mosi'])
    # Hardware SPI configuration:
    SPI_PORT = 0
    SPI_DEVICE = 0
    mcp = Adafruit_MCP3008.MCP3008(spi=SPI.SpiDev(SPI_PORT, SPI_DEVICE))

    # sensor = RPi_AS3935(address=0x00, bus=1)

    # sensor.set_indoors(True)
    # sensor.set_noise_floor(0)
    # sensor.calibrate(tun_cap=0x0F)

    data = WeatherData()
    lastrainevent = datetime.datetime.now()
    GPIO.setup(cfg.configs['windspeed']['pin'], GPIO.IN,
               pull_up_down=GPIO.PUD_UP)
    GPIO.setup(cfg.configs['raingauge']['pin'], GPIO.IN,
               pull_up_down=GPIO.PUD_UP)

    GPIO.add_event_detect(cfg.configs['windspeed']['pin'], GPIO.FALLING)
    GPIO.add_event_callback(cfg.configs['windspeed']['pin'], windEventHandler)

    GPIO.add_event_detect(cfg.configs['raingauge']['pin'], GPIO.FALLING)
    GPIO.add_event_callback(cfg.configs['raingauge']['pin'], rainEventHandler)

    # GPIO.setup(cfg.configs['lightning']['pin'], GPIO.IN)
    # GPIO.add_event_detect(cfg.configs['lightning']['pin'],
    #                       GPIO.RISING, callback=handle_interrupt)

    while True:
        start = datetime.datetime.now()

        # print(sorted(list(data._dumprow)))
        bmp.measure_pressure()
        data.temp = bmp.temperature
        data.pressure = bmp.pressure
        # print("Temperature: " + data.tempF + " deg F")
        # print("Temperature: " + data.tempC + " deg C")
        # print("Pressure : " + data.pressureMillibar + " millibar")
        # print("Pressure : " + data.pressureInchesHG + " inches-Hg")

        (tempc, data.ds18b20temp) = data.ds18b20_read_temp()
        # print("1-wire temp: " + str(data.ds18b20temp))

        humidity, temperature = Adafruit_DHT.read(11, 5)
        if humidity is not None and temperature is not None:
            data.humidityDHT = humidity
            data.temperatureDHT = temperature
            # print('Temp={0:0.1f}*C  Humidity={1:0.1f}%'.format(
            #    temperature, humidity))
        else:
            # if datalast is not None:
            #    humidity = datalast.humidityDHT
            #    temperature = datalast.temperatureDHT
            print('Failed to get reading. Try again!')

        # Analog Readings
        values = [0]*5
        for i in range(5):
            # The read_adc function will get the value
            # of the specified channel (0-7).
            values[i] = mcp.read_adc(i)
        # Print the ADC values.
        # print('| {0:>4} | {1:>4} | {2:>4} | {3:>4} |\
# {4:>4} '.format(*range(8)))
#        print('-' * 57)
#        print('| {0:>4} | {1:>4} | {2:>4} | {3:>4} |\
# {4:>4} '.format(*values))

        data.air1 = values[cfg.configs['air1']['analog-ch']]
        data.air2 = values[cfg.configs['air2']['analog-ch']]
        data.light = values[cfg.configs['lightresistor']['analog-ch']]
        data.soilmoisture = values[cfg.configs['soilmoisture']['analog-ch']]
        data.winddir = values[cfg.configs['winddir']['analog-ch']]
        # print("Wind: " + data.getwinddir(data.winddir))
        # Output:
        now = datetime.datetime.utcnow()
        earlier = datetime.datetime.strptime(data.timeUTC,
                                             '%Y-%m-%d %H:%M:%S.%f')
        # print("St Sec: " + str(e.second) + " " + str(e.microsecond))
        # print("Now   Sec: " + str(now.second) + " " + str(now.microsecond))
        data.tdelta = (now - earlier).total_seconds()
        print("Delta:" + str(data.tdelta))
        print("Data:")
        print(list(data.exportdata()))

        sql = """INSERT into weatherdata (measurement, tdelta, bmp_temp_f,
              bmp_pressuer_millibar, dht_temp_f, dht_humidity_perc,
              light_reading, wind_dir_value, wind_dir_lookup,
              wind_speed_count, rain_count, soil_temp, soil_humidity,
              air_1,  air_2, data_version) values
              (%s,%s, %s,%s,%s,%s,%s,%s,%s,%s,%s,%s,%s,%s,%s, %s)"""
        insertdata = list(data.exportdata())

        try:
            cursor.execute(sql, insertdata)
            conn.commit()
        except (Exception, psycopg2.DatabaseError) as error:
            print(error)
            print("SQL statement:" + sql)
            print("Data: " + str(insertdata))
            conn.rollback()

        dataout = dataout.writedata(data.exportdata())
        # dataout.fileday = now.day
        # print ("Desc: ")
        # print(data.describedata())
        # datalast = data
        data = WeatherData()
        # time.sleep(0.15)

    exit(0)

    daemon = WeatherDaemon('/tmp/weatherdaemon.pid')
    if len(sys.argv) == 2:
        if 'start' == sys.argv[1]:
            logger.info("Starting up...")
            daemon.start()
        elif 'stop' == sys.argv[1]:
            logger.info("Shutting down...")
            daemon.stop()
        elif 'restart' == sys.argv[1]:
            logger.info("Restarting...")
            daemon.restart()
        else:
            print("Unknown command")
            sys.exit(2)
            # sys.exit(0)
    else:
        print("usage: %s start|stop|restart" % sys.argv[0])
        sys.exit(2)

    # Date Calcs
    tomorrow = datetime.date.today() + datetime.timedelta(days=1)
    logger.debug("Tomorrow: " + str(tomorrow.month) + " " + str(tomorrow.day))

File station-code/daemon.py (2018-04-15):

"""Generic linux daemon base class for python 3.x."""

import sys
import os
import time
import atexit
import signal


class Daemon:
    """A generic daemon class.
    Usage: subclass the daemon class and override the run() method."""

    def __init__(self, pidfile): self.pidfile = pidfile

    def daemonize(self):
        """Deamonize class. UNIX double fork mechanism."""

        try:
            pid = os.fork()
            if pid > 0:
                # exit first parent
                sys.exit(0)
        except OSError as err:
            sys.stderr.write('fork #1 failed: {0}\n'.format(err))
            sys.exit(1)

        # decouple from parent environment
        os.chdir('/')
        os.setsid()
        os.umask(0)

        # do second fork
        try:
            pid = os.fork()
            if pid > 0:

                # exit from second parent
                sys.exit(0)
        except OSError as err:
            sys.stderr.write('fork #2 failed: {0}\n'.format(err))
            sys.exit(1)

        # redirect standard file descriptors
        sys.stdout.flush()
        sys.stderr.flush()
        si = open(os.devnull, 'r')
        so = open(os.devnull, 'a+')
        se = open(os.devnull, 'a+')

        os.dup2(si.fileno(), sys.stdin.fileno())
        os.dup2(so.fileno(), sys.stdout.fileno())
        os.dup2(se.fileno(), sys.stderr.fileno())

        # write pidfile
        atexit.register(self.delpid)

        pid = str(os.getpid())
        with open(self.pidfile, 'w+') as f:
            f.write(pid + '\n')

    def delpid(self):
        os.remove(self.pidfile)

    def start(self):
        """Start the daemon."""

        # Check for a pidfile to see if the daemon already runs
        try:
            with open(self.pidfile, 'r') as pf:

                pid = int(pf.read().strip())
        except IOError:
            pid = None

        if pid:
            message = "pidfile {0} already exist. " + \
                    "Daemon already running?\n"
            sys.stderr.write(message.format(self.pidfile))
            sys.exit(1)

        # Start the daemon
        self.daemonize()
        self.run()

    def stop(self):
        """Stop the daemon."""

        # Get the pid from the pidfile
        try:
            with open(self.pidfile, 'r') as pf:
                pid = int(pf.read().strip())
        except IOError:
            pid = None

        if not pid:
            message = "pidfile {0} does not exist. " + \
                    "Daemon not running?\n"
            sys.stderr.write(message.format(self.pidfile))
            return  # not an error in a restart

        # Try killing the daemon process
        try:
            while 1:
                os.kill(pid, signal.SIGTERM)
                time.sleep(0.0001)
        except OSError as err:
            e = str(err.args)
            if e.find("No such process") > 0:
                if os.path.exists(self.pidfile):
                    os.remove(self.pidfile)
            else:
                print(str(err.args))
                sys.exit(1)

    def restart(self):
        """Restart the daemon."""
        self.stop()
        self.start()

    def run(self):
        """You should override this method when you subclass Daemon.

        It will be called after the process has been daemonized by
        start() or restart()."""

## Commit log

2015-03-28 API reference added, more notes, change in RRD format for pressure
2015-04-01 Switching to python demon instead of perl, easier Pi libraries
2015-04-01 Fixed config location for cron, created OnceAday scrip to get two json history files and symlink them to current, closes #2 and closes #4
2015-04-06 Python daemon, reading temp, humidity, pressure, button, gps, etc. Writes to CSV
2015-04-07 Added interrupts for wind speed and rain
2015-04-07 Added Camera capabilities
2015-04-07 Script to be run as cronjob to get latest image from camera
2015-11-07 Added incomplete circuit diagram
    [raspberrypiweatherstation.fzz]
2017-07-12 Initial Changes, readme, new diagram, started with DS18b20 1-wire temp sensor
    [raspberrypiweatherstation.fzz]
2017-07-22 Snapshot, switching up code, rebuilding.
    [Enclosure.skp, raspberrypiweatherstation.fzz]
2017-07-23 Started to layout PCB in diagram, added Winddir to test, need to test functionality and code for it
    [raspberrypiweatherstation.fzz]
2017-08-01 Starting to add in sensor data
2017-08-02 Snapshot after working with Pressure and Humidity
2018-02-05 Initial Commit/Framework
2018-02-23 Switched bmp from BOARD to BCM
2018-02-23 Added 1-wire, needs cleanup
2018-03-29 Added Circuit Diagram and PDF exports for printing to thermal transfer paper
    [StationCircuitBoards.fzz]
2018-04-15 updates for wind, latest working code, need to fix file switchover bug
    [StationCircuitBoards.fzz]
2018-05-01 Working, added Frontend for Google Charts (not great), disabled lightning detector due to issues
    [collectweather.py]
